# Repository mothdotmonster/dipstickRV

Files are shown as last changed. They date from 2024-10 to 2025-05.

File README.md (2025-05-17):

# dipstickRV
adorably small CH32V003 devboard

[buy it here](https://mothdotmonster-shop.square.site/product/dipstickrv/7)



includes user-LED on PD6 and [rv003usb](https://github.com/cnlohr/rv003usb)-compatible USB-C port

uses [Paw-Connect](https://github.com/LeoDJ/Paw-Connect)

pinout

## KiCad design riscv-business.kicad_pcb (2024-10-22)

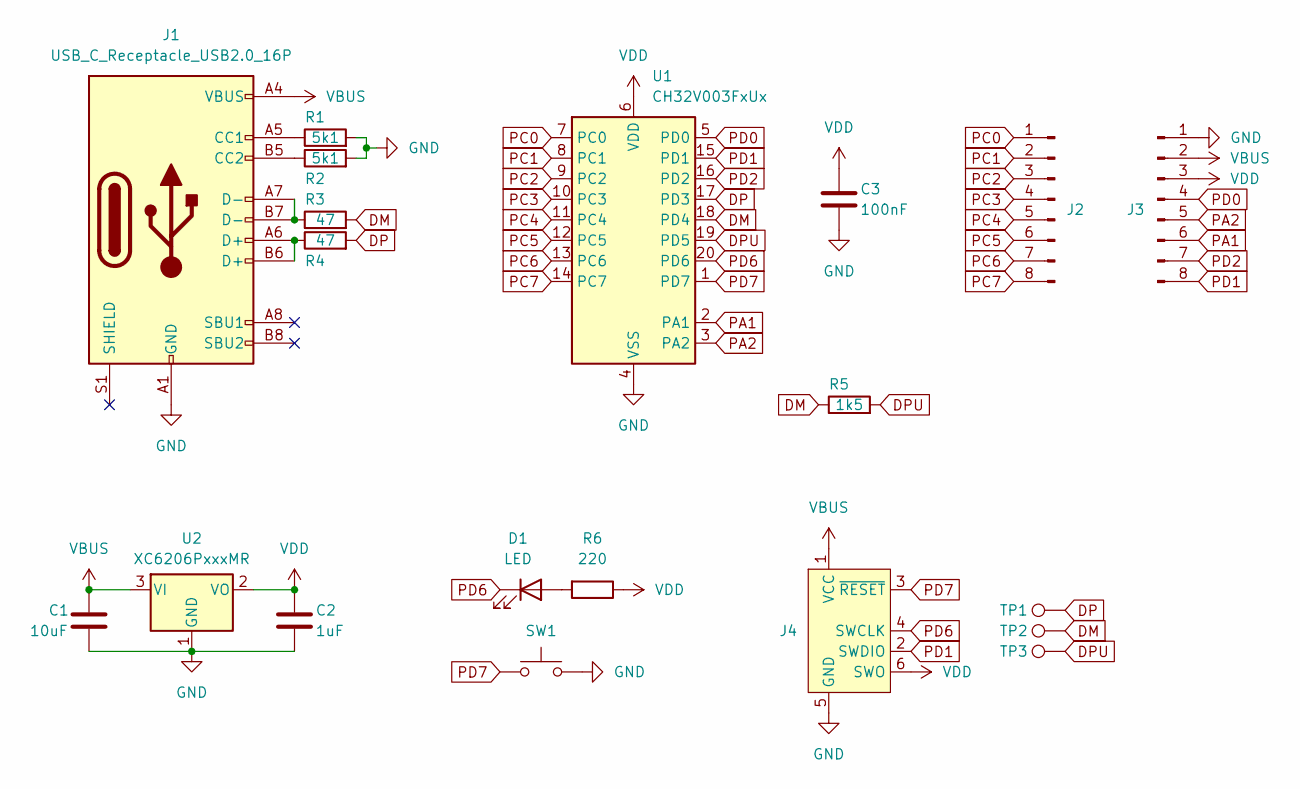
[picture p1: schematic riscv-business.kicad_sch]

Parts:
C1: 10uF; C_0402_1005Metric; JLC C15525
C2: 1uF; C_0402_1005Metric; JLC C52923
C3: 100nF; C_0402_1005Metric; JLC C1525
D1: LED; LED_0603_1608Metric; JLC C2286
J1: USB_C_Receptacle_USB2.0_16P; USB_C_Receptacle_HCTL_HC-TYPE-C-16P-01A; JLC C2765186
J2, J3: Conn_01x08_Pin; PinHeader_1x08_P2.54mm_Vertical
J4: Conn_ARM_SWD_TagConnect_TC2030-NL; Paw-Connect_RevA_TC2030-IDC-NL_2x03_P1.27mm_Vertical
R1, R2: 5k1; R_0402_1005Metric; JLC C25905
R3, R4: 47; R_0402_1005Metric; JLC C25105
R5: 1k5; R_0402_1005Metric; JLC C25867
R6: 220; R_0402_1005Metric; JLC C25091
SW1: SW_Push; Panasonic-EVPAW-2x3mm; JLC C2858607
TP1, TP2, TP3: TestPoint; TestPoint_Pad_D1.0mm
U1: CH32V003FxUx; QFN-20-1EP_3x3mm_P0.4mm_EP1.65x1.65mm; JLC C5299908
U2: XC6206PxxxMR; SOT-23-3; JLC C5446

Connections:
DM: R3.2, R5.1, TP2.1, U1.18 (PD4)
DP: R4.2, TP1.1, U1.17 (PD3)
DPU: R5.2, TP3.1, U1.19 (PD5)
GND: C1.2, C2.2, C3.2, J1.A1 (GND), J1.A12 (GND), J1.B1 (GND), J1.B12 (GND), J3.1, J4.5 (GND), R1.2, R2.2, SW1.2, U1.4 (VSS), U1.21 (VSS), U2.1 (GND)
unnamed: D1.2 (A), R6.2
unnamed: J1.A5 (CC1), R1.1
unnamed: J1.B5 (CC2), R2.1
unnamed: J1.A6 (D+), J1.B6 (D+), R4.1
unnamed: J1.A7 (D-), J1.B7 (D-), R3.1
PA1: J3.6, U1.2 (PA1)
PA2: J3.5, U1.3 (PA2)
PC0: J2.1, U1.7 (PC0)
PC1: J2.2, U1.8 (PC1)
PC2: J2.3, U1.9 (PC2)
PC3: J2.4, U1.10 (PC3)
PC4: J2.5, U1.11 (PC4)
PC5: J2.6, U1.12 (PC5)
PC6: J2.7, U1.13 (PC6)
PC7: J2.8, U1.14 (PC7)
PD0: J3.4, U1.5 (PD0)
PD1: J3.8, J4.2 (SWDIO), U1.15 (PD1)
PD2: J3.7, U1.16 (PD2)
PD6: D1.1 (K), J4.4 (SWCLK), U1.20 (PD6)
PD7: J4.3 (~RESET), SW1.1, U1.1 (PD7)
VBUS: C1.1, J1.A4 (VBUS), J1.A9 (VBUS), J1.B4 (VBUS), J1.B9 (VBUS), J3.2, J4.1 (VCC), U2.3 (VI)
VDD: C2.1, C3.1, J3.3, J4.6 (SWO), R6.1, U1.6 (VDD), U2.2 (VO)

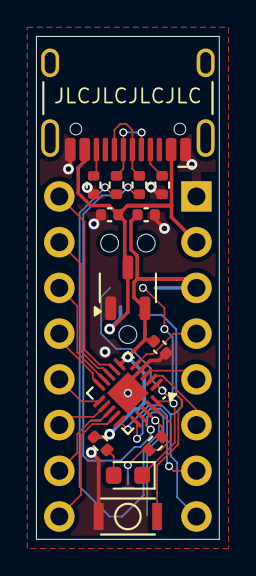
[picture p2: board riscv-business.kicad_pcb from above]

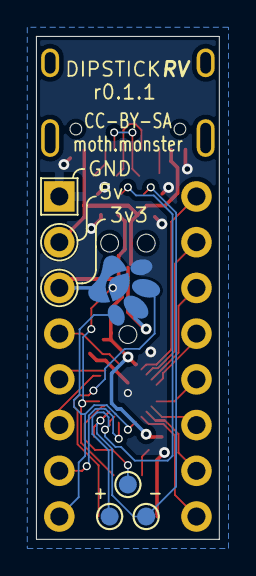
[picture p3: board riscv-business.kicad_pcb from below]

Board: 2 copper layers, 10.2 x 27.9 mm, 20 parts (6 on the bottom side), 26 nets.

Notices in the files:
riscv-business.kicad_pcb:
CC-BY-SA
